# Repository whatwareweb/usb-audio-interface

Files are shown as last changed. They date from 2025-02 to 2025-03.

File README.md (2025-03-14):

# usb-audio-interface
USB audio interface based on PCM2906C IC

**NOTE: This design is tested to work properly. If you have any problems using this design, feel free to send me an email or leave a GitHub issue.**

Assembled and tested PCB

## description
This USB audio interface board has standard RCA inputs and outputs for both analog and digital signals. I designed it because the only products that exist that can record digital S/PDIF over coaxial cost >$200 USD.

While it was designed primarily for digital audio capture and output, I also put thought into the analog design. It has high-capacitance, low ESR output capacitors for good low-frequency response, and an optimized layout for decoupling capacitors and crystal circuitry, to improve ADC/DAC performance, and to reduce jitter, respectively, while maintaining a super compact form factor of only 4x5cm. It could have been even more compact, but at the expense of removing industry standard RCA jacks.

## assembly
The BOM in the KiCAD project is up to date and contains no out-of-production parts at time of creation. All parts were ordered from Mouser Electronics. This was designed to be hand solderable, with SMD components including larger pads in the footprint, however as it does use 0603 components, reflow soldering is preferable if possible.

## features
 - USB-C port with reversibility support
 - Low ESR high capacitance output and input capacitors for good low-frequency response
 - Analog and digital inputs and outputs
 - Compact design layout
 - Standard RCA jacks

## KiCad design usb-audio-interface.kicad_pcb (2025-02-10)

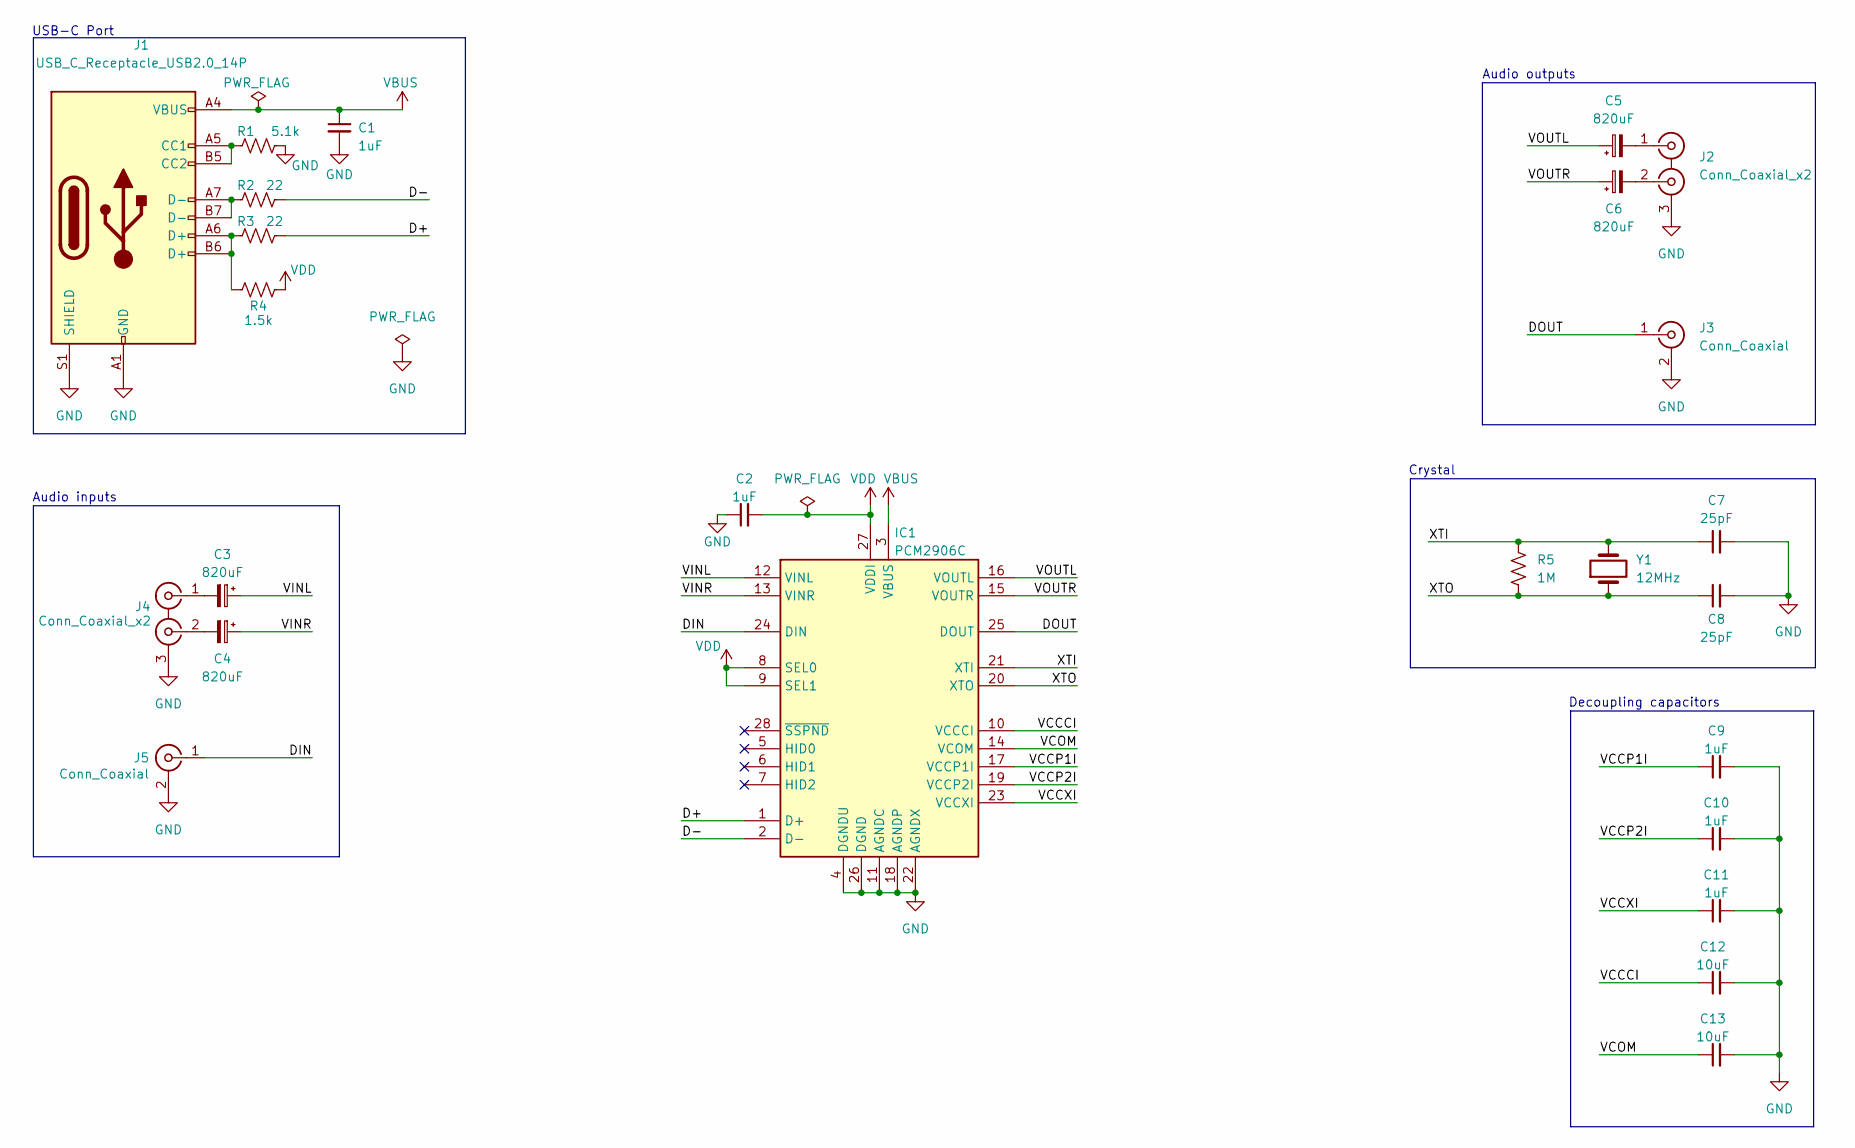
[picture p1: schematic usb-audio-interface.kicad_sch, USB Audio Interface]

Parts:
C1: 1uF; C_0603_1608Metric_Pad1.08x0.95mm_HandSolder; Mfr. # FG28X7R1E105KRT00
C2, C9, C10, C11: 1uF; C_0603_1608Metric_Pad1.08x0.95mm_HandSolder; Manufacturer_Part_Number CL10A105KQ8NNNC
C3, C4, C5, C6: 820uF; CP_Radial_D8.0mm_P3.50mm; Manufacturer_Part_Number 6.3ZLH820MEFC8X11.5
C7, C8: 25pF; C_0603_1608Metric_Pad1.08x0.95mm_HandSolder; Manufacturer_Part_Number CC0603JRNPO9BN250
C12, C13: 10uF; C_0805_2012Metric_Pad1.18x1.45mm_HandSolder; Manufacturer_Part_Number CL21A106KOQNNNG
IC1: PCM2906C; SSOP-28_5.3x10.2mm_P0.65mm; Mouser Part Number 595-PCM2906CDBR
J1: USB_C_Receptacle_USB2.0_14P; USB_C_Receptacle_GCT_USB4105-xx-A_16P_TopMnt_Horizontal; Mfr. # USB4105
J2, J4: Conn_Coaxial_x2; PJRAN2X1U01AUX; Manufacturer_Part_Number PJRAN2X1U01AUX
J3, J5: Conn_Coaxial; 1560099E; Manufacturer_Part_Number 156-0099-E
R1: 5.1k; R_0603_1608Metric_Pad0.98x0.95mm_HandSolder; Mfr. # CF18JT5K10
R2, R3: 22; R_0603_1608Metric_Pad0.98x0.95mm_HandSolder; Mfr. # CFR-12JB-52-30R
R4: 1.5k; R_0603_1608Metric_Pad0.98x0.95mm_HandSolder; Manufacturer_Part_Number CRGCQ0603F1K5
R5: 1M; R_0603_1608Metric_Pad0.98x0.95mm_HandSolder; Manufacturer_Part_Number RK73B1JTTDD105J
Y1: 12MHz; Crystal_SMD_HC49-SD; Manufacturer_Part_Number ABLS-12.000MHz-B4H-T

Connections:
/D+: IC1.1 (D+), R3.2
/D-: IC1.2 (D-), R2.2
/DIN: IC1.24 (DIN), J5.1 (In)
/DOUT: IC1.25 (DOUT), J3.1 (In)
/VCCCI: C12.1, IC1.10 (VCCCI)
/VCCP1I: C9.1, IC1.17 (VCCP1I)
/VCCP2I: C10.1, IC1.19 (VCCP2I)
/VCCXI: C11.1, IC1.23 (VCCXI)
/VCOM: C13.1, IC1.14 (VCOM)
/VINL: C3.1, IC1.12 (VINL)
/VINR: C4.1, IC1.13 (VINR)
/VOUTL: C5.1, IC1.16 (VOUTL)
/VOUTR: C6.1, IC1.15 (VOUTR)
/XTI: C7.1, IC1.21 (XTI), R5.1, Y1.2
/XTO: C8.1, IC1.20 (XTO), R5.2, Y1.1
GND: C1.2, C2.1, C7.2, C8.2, C9.2, C10.2, C11.2, C12.2, C13.2, IC1.4 (DGNDU), IC1.11 (AGNDC), IC1.18 (AGNDP), IC1.22 (AGNDX), IC1.26 (DGND), J1.A1 (GND), J1.A12 (GND), J1.B1 (GND), J1.B12 (GND), J1.S1 (SHIELD), J2.3 (EXT), J3.2 (Ext), J4.3 (EXT), J5.2 (Ext), R1.2
unnamed: J1.A5 (CC1), J1.B5 (CC2), R1.1
unnamed: J1.A6 (D+), J1.B6 (D+), R3.1, R4.1
unnamed: J1.A7 (D-), J1.B7 (D-), R2.1
unnamed: C5.2, J2.1 (IN1)
unnamed: C6.2, J2.2 (IN2)
unnamed: C3.2, J4.1 (IN1)
unnamed: C4.2, J4.2 (IN2)
VBUS: C1.1, IC1.3 (VBUS), J1.A4 (VBUS), J1.A9 (VBUS), J1.B4 (VBUS), J1.B9 (VBUS)
VDD: C2.2, IC1.8 (SEL0), IC1.9 (SEL1), IC1.27 (VDDI), R4.2

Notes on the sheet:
Audio outputs
Crystal
USB-C Port
Audio inputs
Decoupling capacitors

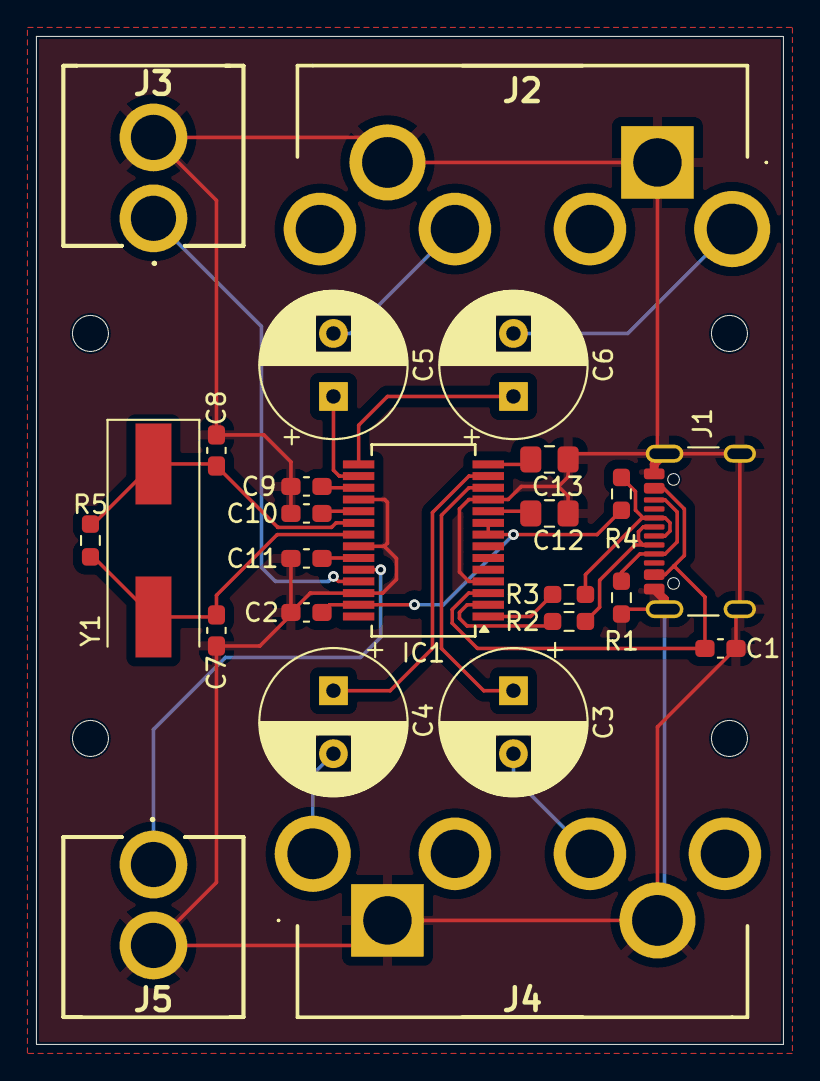
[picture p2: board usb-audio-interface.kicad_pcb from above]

Board: 2 copper layers, 41.5 x 56.0 mm, 25 parts (0 on the bottom side), 25 nets.

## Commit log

2025-01-27 Initial schematic
2025-01-27 Update schematic and start on footprints
    [usb-audio-interface.kicad_sch]
2025-01-28 finish schematic
    [usb-audio-interface.kicad_sch]
2025-01-28 update pcb
    [usb-audio-interface.kicad_pcb]
2025-01-29 finish pcb
    [usb-audio-interface.kicad_pcb, usb-audio-interface.kicad_sch]
2025-02-01 update schematic
    [usb-audio-interface.kicad_pcb]
2025-02-10 track width for crystal
    [usb-audio-interface.kicad_pcb]
2025-02-10 finish board
    [usb-audio-interface.kicad_pcb]
2025-02-10 update bom
    [usb-audio-interface.kicad_sch]
2025-02-10 add mounting holes
    [usb-audio-interface.kicad_pcb]
